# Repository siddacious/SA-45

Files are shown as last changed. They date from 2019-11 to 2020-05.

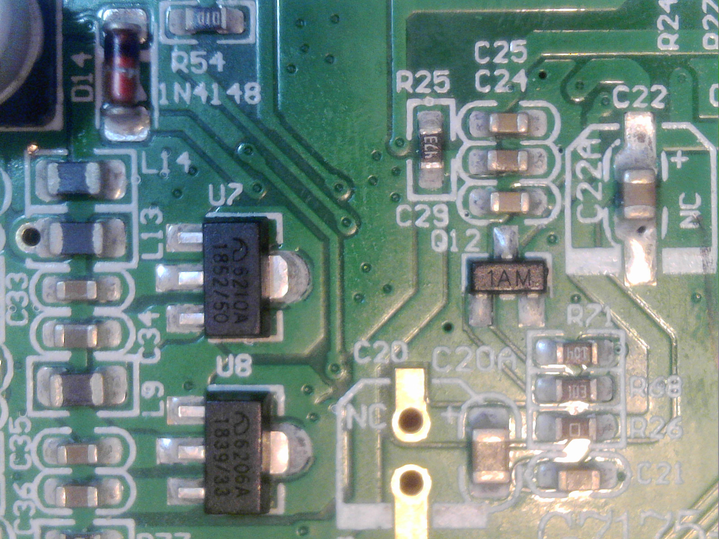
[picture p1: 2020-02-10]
images/S20190909_008.jpg

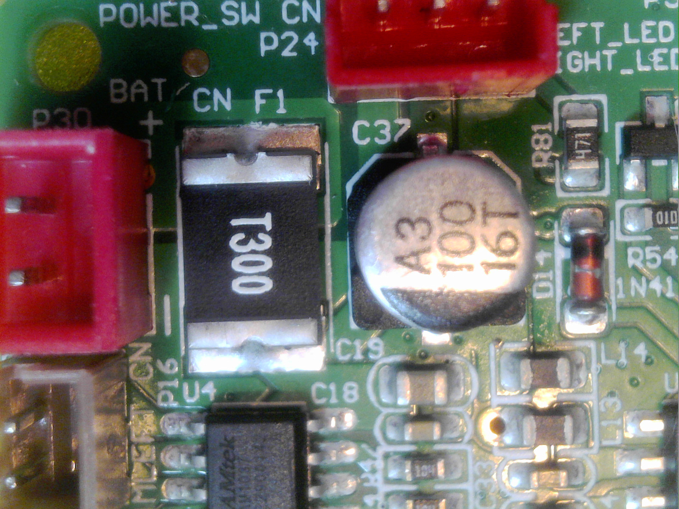
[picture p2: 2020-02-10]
images/S20190909_004.jpg

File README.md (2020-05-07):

# SA-45 - Useful info for playing doctor with your robot friend

All Software is released under the MIT license. See [MIT.txt](MIT.txt)

All Schematics and artwork is released as CC-BY-SA 4.0. See [CC-BY-SA_40.txt](CC-BY-SA_40.txt)

* [`droid-bb8_schematic.pdf`](droid-bb8_schematic.pdf) by @russdill
* [`nrf_extract/`](nrf_extract/) by @ruthsaurian
* [`nrf_extract_edits`](nrf_extract_edits/) by @siddacious and @ruthsaurian
* all other content by @siddacious

## More cool stuff
* by @russdill [here](https://github.com/russdill/droid_depot)
* by @ruthsaurian [here](https://github.com/ruthsarian/pxt-swge-beacon)
* SWGE discord: https://discord.gg/nsa9wCz

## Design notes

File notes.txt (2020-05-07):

# reference:
https://blog.includesecurity.com/2015/11/NordicSemi-ARM-SoC-Firmware-dumping-technique.html
https://www.pentestpartners.com/security-blog/nrf51822-code-readout-protection-bypass-a-how-to/

# Includes how to convert a .bin to 
https://ncrmnt.org/2019/04/14/note-to-self-how-to-flash-bin-files-via-raw-gdb/

# openocd startup using j-link
openocd.exe -f interface\jlink.cfg  -c "transport select swd" -c "adapter_khz 6000" -f target\nrf51.cfg

# openocd command to reset and halt the processor
reset halt

# scripts
# for me, found instructions that didn't help or I used wrong. Ended up using the instruction and register that Ruthsarian used -sidd
drop.py   : searches for an instruction that will write contents of a memory address to 

# original version switches the endianness
pickup.py : using the instruction found with drop.py, will read back the contents of flash memory

# Command to convert the extracted .bin to .hex for programming:
arm-none-eabi-objcopy -I binary -B arm -O ihex -S backup.bin backup.hex

#to program via SWD & JLink:
nrfjprog -f nrf51 --program backup.hex

[9:24 PM]  Ruthsarian: my basic understanding is there are two serial lines (each with their own clock, so 4 wires total) between the bluetooth and audio microcontrollers. i did do several captures on those lines with a logic analyzer.
bluetooth controller sends commands to the audio controller to tell it what to play. those commands come in the form of two bytes. the first byte is the command (THIS IS ALL ASSUMPTION based on what I've seen) which is always 0x10 followed by a second byte which identifies which group of audio clips the audio controller should play from.
[9:24 PM]  Ruthsarian: at startup or when a new personality chip is inserted, there is a bunch more data that is send between them. i can pick out personality chip ID and affiliation ID from them.
[9:25 PM]  Ruthsarian: but without any captures from an R2 I can't confirm whether or not there's a difference (such as a "HEY I'm an R2!"
[9:26 PM]  Cowkitty | Dead Bothans: @Mia Honestly, I’d recommend a different approach: we’ve confirmed the droid controller sends different commands per button, so it’s the BB firmware that’s deciding to just use the accessory unique button code to play sounds. I’d look into seeing what the firmware does when it sees that button code, and look into modding that. Problem is you might not have a pin already wired/accessible to send power to like the R2 units. Not sure— we haven’t done a tear down on both to compare yet.
[9:26 PM]  Ruthsarian: also, with the bb unit at least, that 'play sound' command is the same whether you're pressing the 'accessory' or sound button.
[9:27 PM]  Ruthsarian: from bb's bluetooth microcontroller to the audio controller
[9:29 PM]  Cowkitty | Dead Bothans: Gotcha. Yeah, that’s what I said above. Bb heard unique command from remote, and says “play sound” instead of “power to accessory pin”
[9:30 PM]  Mia: Yeah, that's my ultimate goal, finding the input routine and making the accessory button into a call to "play from blaster sound bank" instead of "play from random sound bank." But to get a breakpoint in there I think I'm gonna have to figure out when it's making a call to the sound chip, then roll up the stack.
[9:31 PM]  Ruthsarian: i've seen schematics that others have made of the bb and r2 hardware. the pinouts for the bluetooth controller are very similar. differences being the accessory detection pins on the R2 are used to read the trimpot in the BB unit. belief being the trimpot controls balancing the two motors in the BB unit so it drives straight.
[9:31 PM]  Cowkitty | Dead Bothans: @Ruthsarian Yeah, that’s what I feared. I didn’t think they’d waste a pin on the BB for that

[9:12 AM]  Mia: You have anything written down about, like, what byte the command is, or what it responds with to represent the two models?
[9:12 AM]  Russ: the serial register for droid model is reg 0x01
[9:12 AM]  Russ: bb series is 2, r2 series is 1
[9:40 AM]  Cowkitty | Dead Bothans: Check the spreadsheet. Already proven those same identifiers are used as beacons, sans chips.
[9:58 AM]  Russ: I know, that one comes from the personality chip
[9:58 AM]  Russ: the default personality chip in the generalplus rom
[9:59 AM]  Russ: hence you only get the value from the installed personality chip instead when one is inserted
[9:59 AM]  holapenguin: if no chip, you can tell.  if has chip, you can't tell, from a beaconing point of view. you're both saying the same thing, no confusion
[10:02 AM]  Russ: the issue is that there are two different droid identifiers. One the droid uses internally, and the other that is tied to the personality chip
[10:41 AM]  Ruthsarian: I did put a logic analyzer on the lines between the nRF (bluetooth) and GP (audio) microcontrollers in the BB droid a while back. I believe there are two separate serial channels (each channel consisting of data line and a clock line). Each channel is one-way. So there's the line from nRF to GP and a second line, GP to NRF. Treating these lines as such, when I 'decode' the data, this is an example of the data I see.
On power on w/no personality chip
    (from gp to nrf)    00 00 00 00 02 00 00 02 00 00 01 00 00 00 00 00 00
    (from nrf to gp)    00 00 01 00 00 08 00 00 0a 00 00 00 00 42 02 0e 1c

On power on w/personality chip (black)
    (from gp to nrf)    80 00 80 00 02 80 00 08 80 00 09 80 00 80 00 80 00
    (from nrf to gp)    00 00 01 00 00 08 00 00 0a 00 00 00 00 42 02 0e 1c

On personality chip insertion (purple)
    (from gp to nrf)    80 00 80 00 07 80 00 01
    (from nrf to gp)    00 00 08 00 00 0a 00 00

On removal of personality chip
    (from gp to nrf)    00 00 00 00 02 00 00 01
    (from nrf to gp)    00 00 08 00 00 0a 00 00

On audio button press
    (from gp to nrf)    80 00
    (from nrf to gp)    10 00
[10:43 AM]  Ruthsarian: However, the audio button press data, for example, matches up with what audio plays. 0x10 being the command to play an audio clip. Then the byte that follows it identifying the group to play an audio clip from (that value being zero-indexed, so 0x00 = audio group 1)
[10:44 AM]  Ruthsarian: and the personality chip insertion and removal seems to include data that matches with the chip being inserted (chip ID and affiliation ID)
[10:45 AM]  Ruthsarian: when reacting to a beacon, the data looks the same as a button press. meaning the nRF chip tells the GP chip what audio group to play from.
[10:57 AM]  Ruthsarian: my interpretation of what the key bytes of the data are
    power on, gp to nrf:
        byte  5 = droid type
        byte  8 = personality chip
        byte 11 = affiliation

    change of personality chip, gp to nrf:
        byte 5 = new personality chip
        byte 8 = affiliation

    play audio (nrf to gp):
        byte 2 = audio group to play from
[11:12 AM]  Russ: @Ruthsarian there's a 5th serial line that the generalplus uses to notify the nrf, eg, when there is a new personality chip
[11:13 AM]  Ruthsarian: is it serial, or is it just change state to notify there's a change. i did see that line and i analyzed it, but i didn't see data on it, just an occasional change in state
[11:14 AM]  Russ: it's like an interrupt
[11:15 AM]  Russ: each serial transaction is an exchange, write byte while reading byte.
[11:15 AM]  Russ: for a reg read, it writes the register to read while reading back a byte it throws away, then writes a zero while reading back the byte
[11:16 AM]  Russ: for reg write, it writes the reg to write while reading back a byte it throws away, then writes the value while reading a value it throws away
[11:16 AM]  Russ: I suspect that the register number indicates where it is going to be a read or a write
[11:17 AM]  Ruthsarian: that is a personality chip being inserted event. the top signal is that 5th line you were talking about.
[11:18 AM]  Russ: 1, 8, and 10 are the only registers I see as read registers
[11:18 AM]  Russ: (droid type, personality chip, affiliation)
[11:19 AM]  Russ: oh, and 0, which seems to be a status bitfield
[11:24 AM]  Mia: So what distinguishes a write on this protocol from a read? Is that image then the lower device saying to the upper device “write register 8: 0000, then write register A: 0000”?
[11:24 AM]  Russ: afaik it's just the register number
[11:25 AM]  Russ: hmm...actually it could be the middle exchange, forgot about that one
[11:25 AM]  Russ: read has three exchanges
[11:26 AM]  Russ: write has 2
[11:26 AM]  Russ: the pattern might just be, exchange 1 - register, exchange 2 - write byte, exchange 3 - read byte
[11:27 AM]  Mia: Hmm. So the difference is then that for a write you just throw away whatever you get back as the read.
[11:27 AM]  Russ: for writes it just does 2 exchanges
[11:30 AM]  Russ: and it looks like on the first exchange the status byte is always returned
[11:44 AM]  Ruthsarian: @Russ the droid type is in register 1? by register do you mean register 1 of the cortex-m0 at the center of the nrf or is that value being stored somewhere else? and can you tell whether or not that value is being checked every time a button press is received? in other words, if I had a debugger connected, could I modify that register value to make the droid think it's another droid?
[11:44 AM]  Russ: the gp
[11:44 AM]  Russ: so you see on the nrf transmit, its 01 00 00, and then from the gp 00 00 02
[11:44 AM]  Russ: that's reading value 2 from reg 1
[11:45 AM]  Russ: there's several droid config things that only happen during boot
[12:48 PM]  holapenguin: for all, see this if you're wanting to use ghirdra collaboratively https://medium.com/@jannis.kirschner/ghidra-collaborative-reversing-1-2-how-to-setup-a-ghidra-server-711f4212912e

 https://discord.gg/pgeEQd

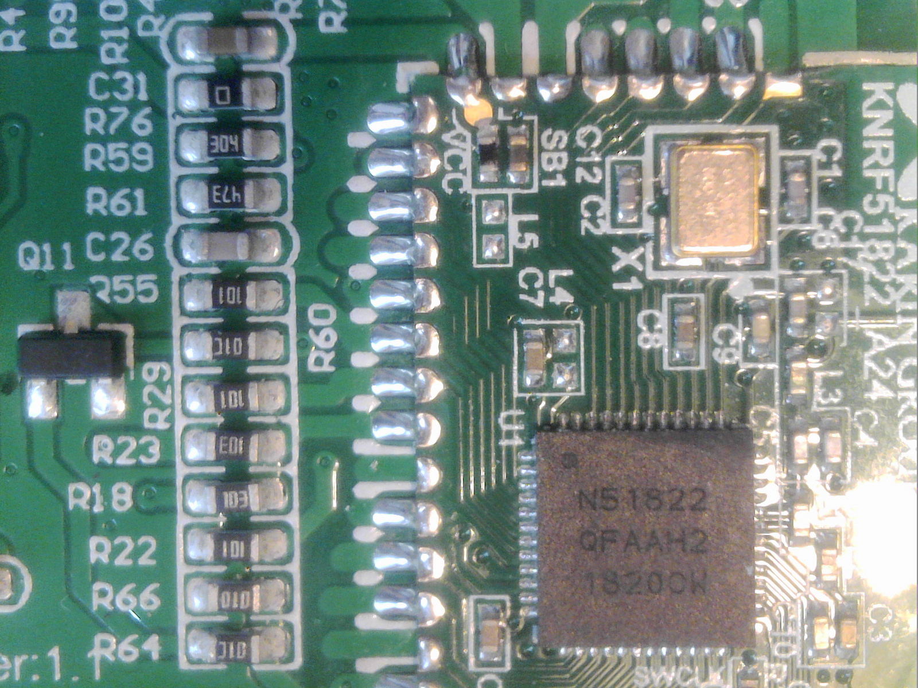
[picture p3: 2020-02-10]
images/S20190909_013.jpg

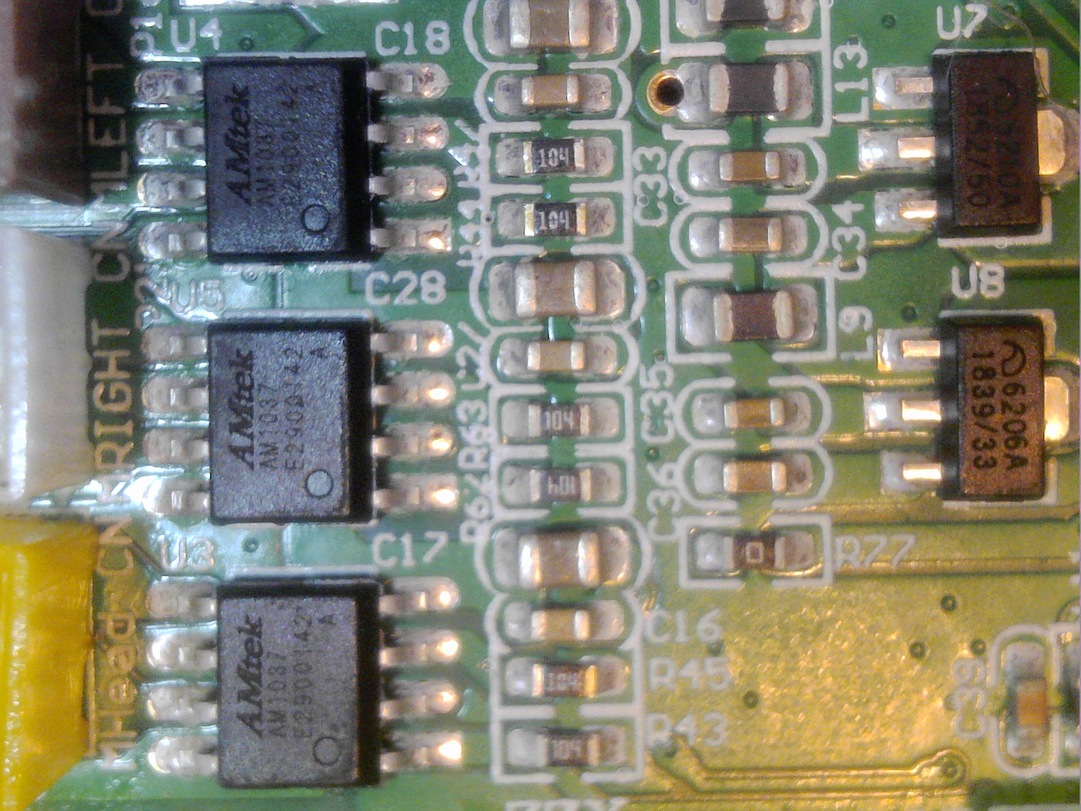
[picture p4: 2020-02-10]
images/S20190909_005.jpg

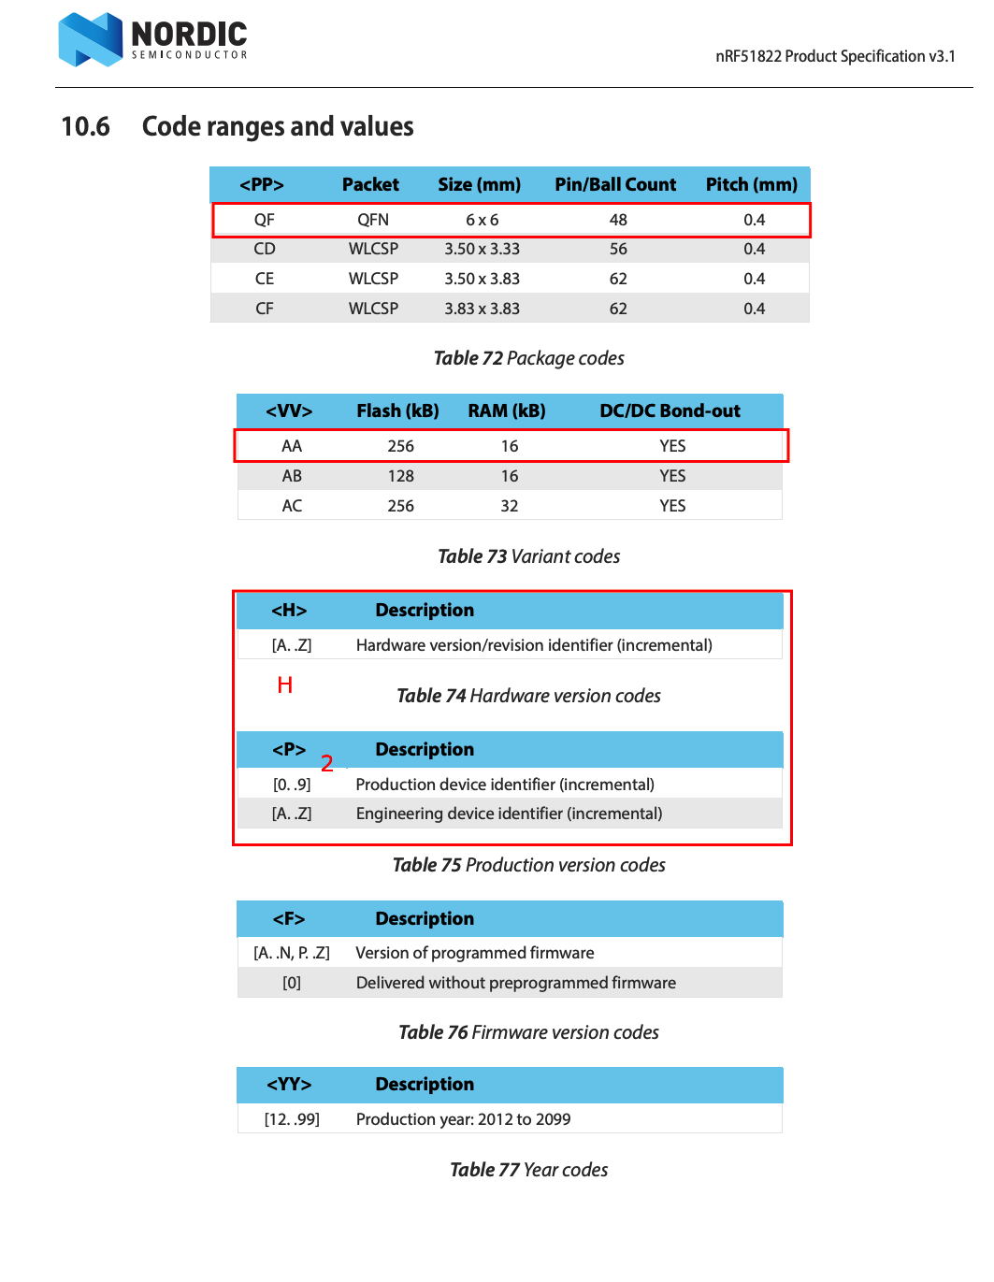
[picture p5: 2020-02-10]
images/nrf_version_info.png

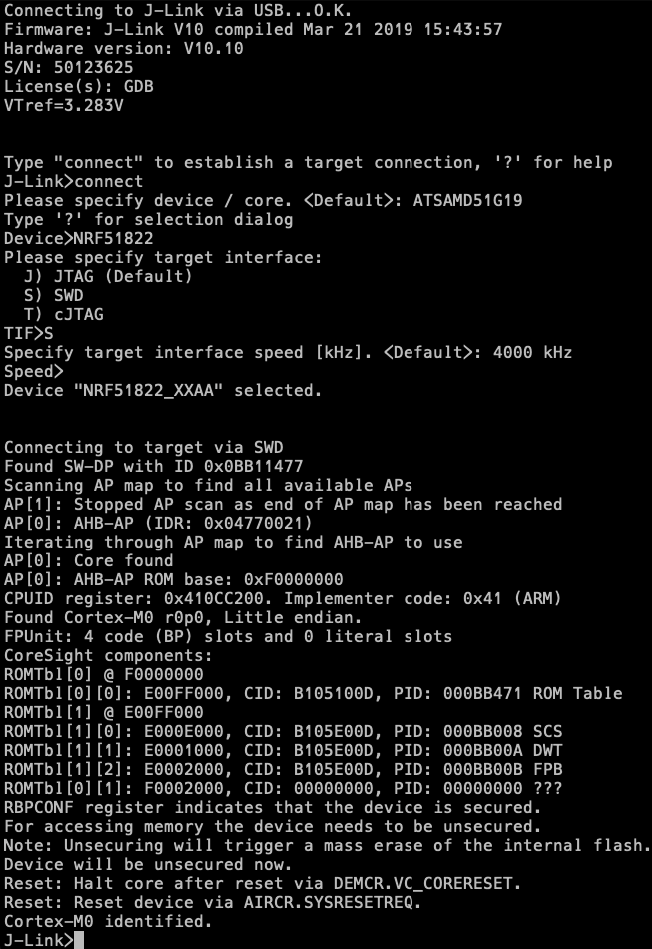
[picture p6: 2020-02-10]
images/initial_connect_nrf.png

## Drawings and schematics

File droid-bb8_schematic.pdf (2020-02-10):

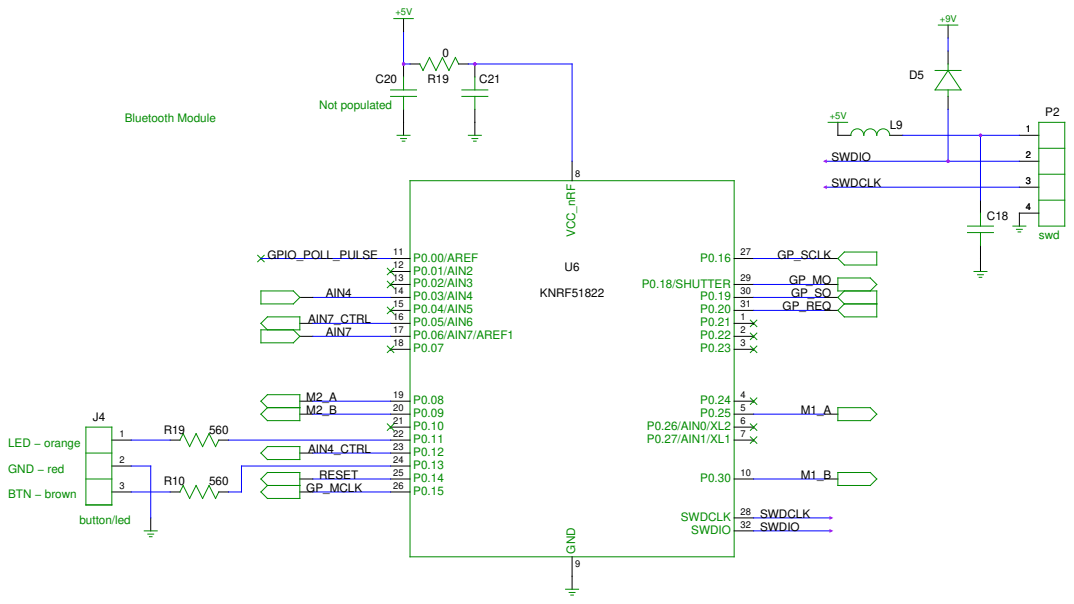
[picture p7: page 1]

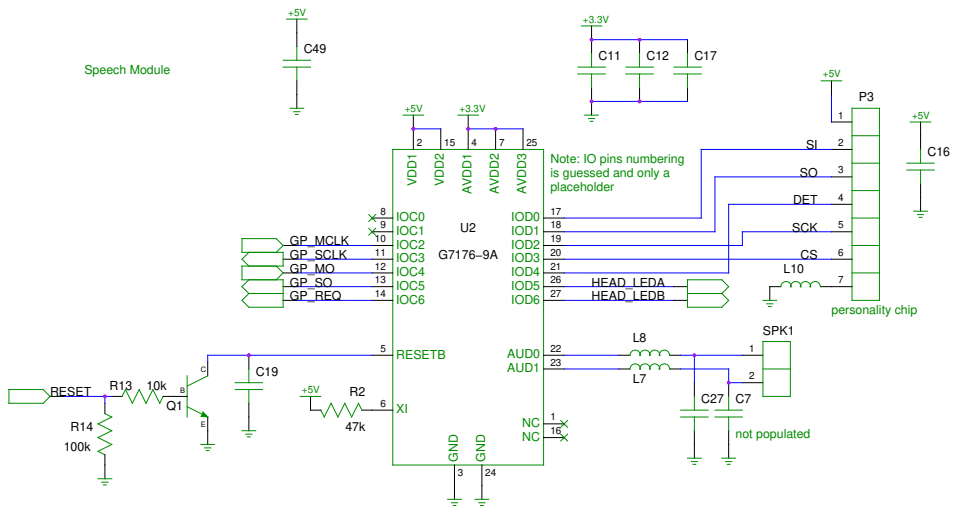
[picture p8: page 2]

Note: IO pins numbering
is guessed and only a
placeholder

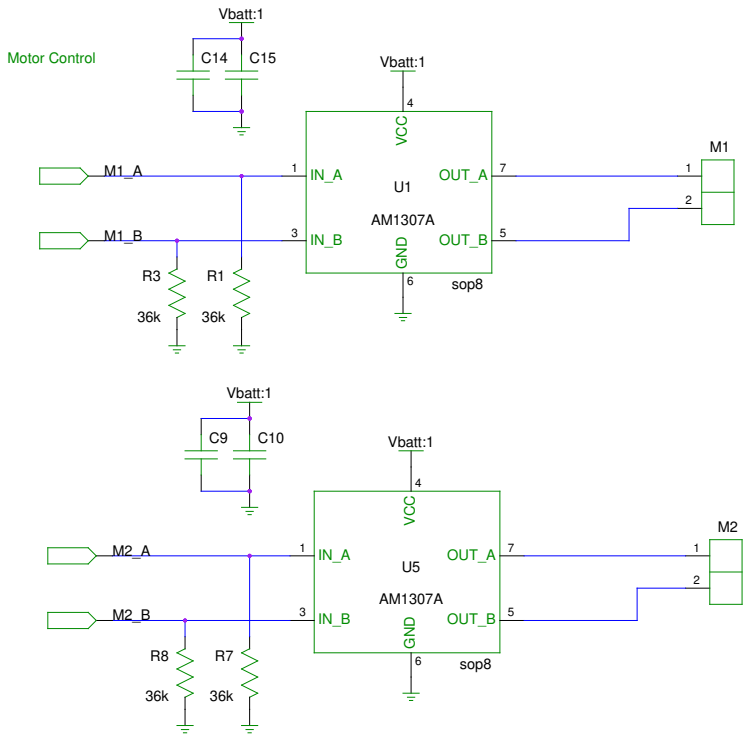
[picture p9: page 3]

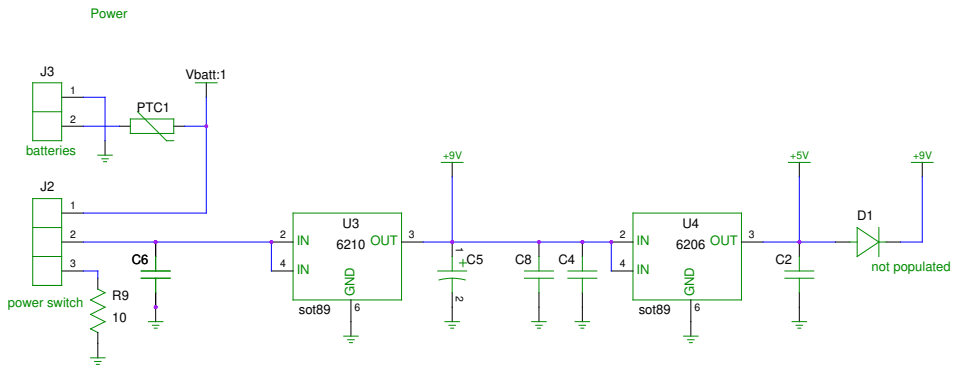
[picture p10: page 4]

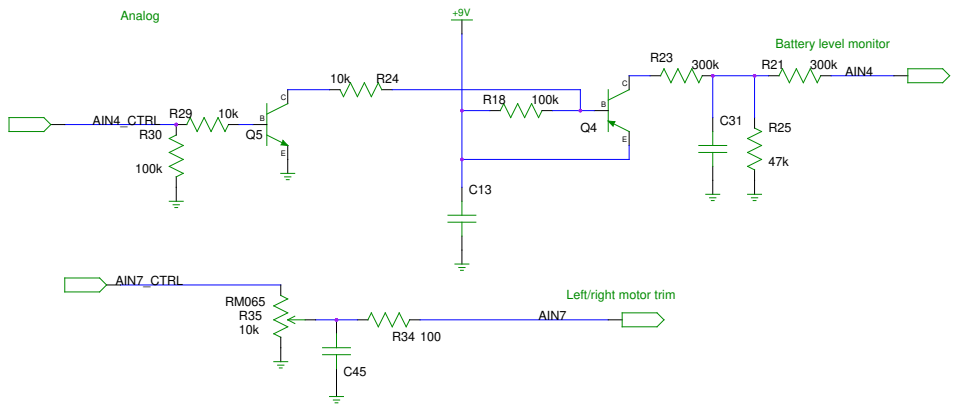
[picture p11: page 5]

Left/right motor trim
AIN7

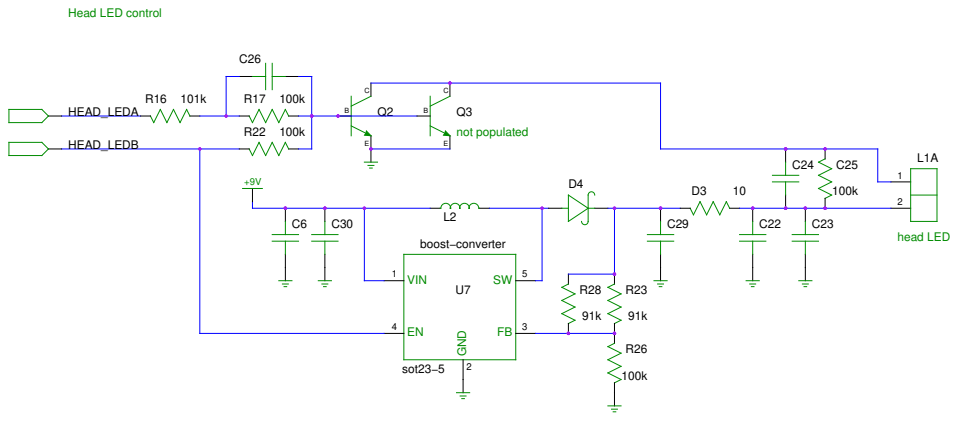
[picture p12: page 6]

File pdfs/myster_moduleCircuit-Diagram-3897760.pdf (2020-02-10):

# Dome Socket

# Main

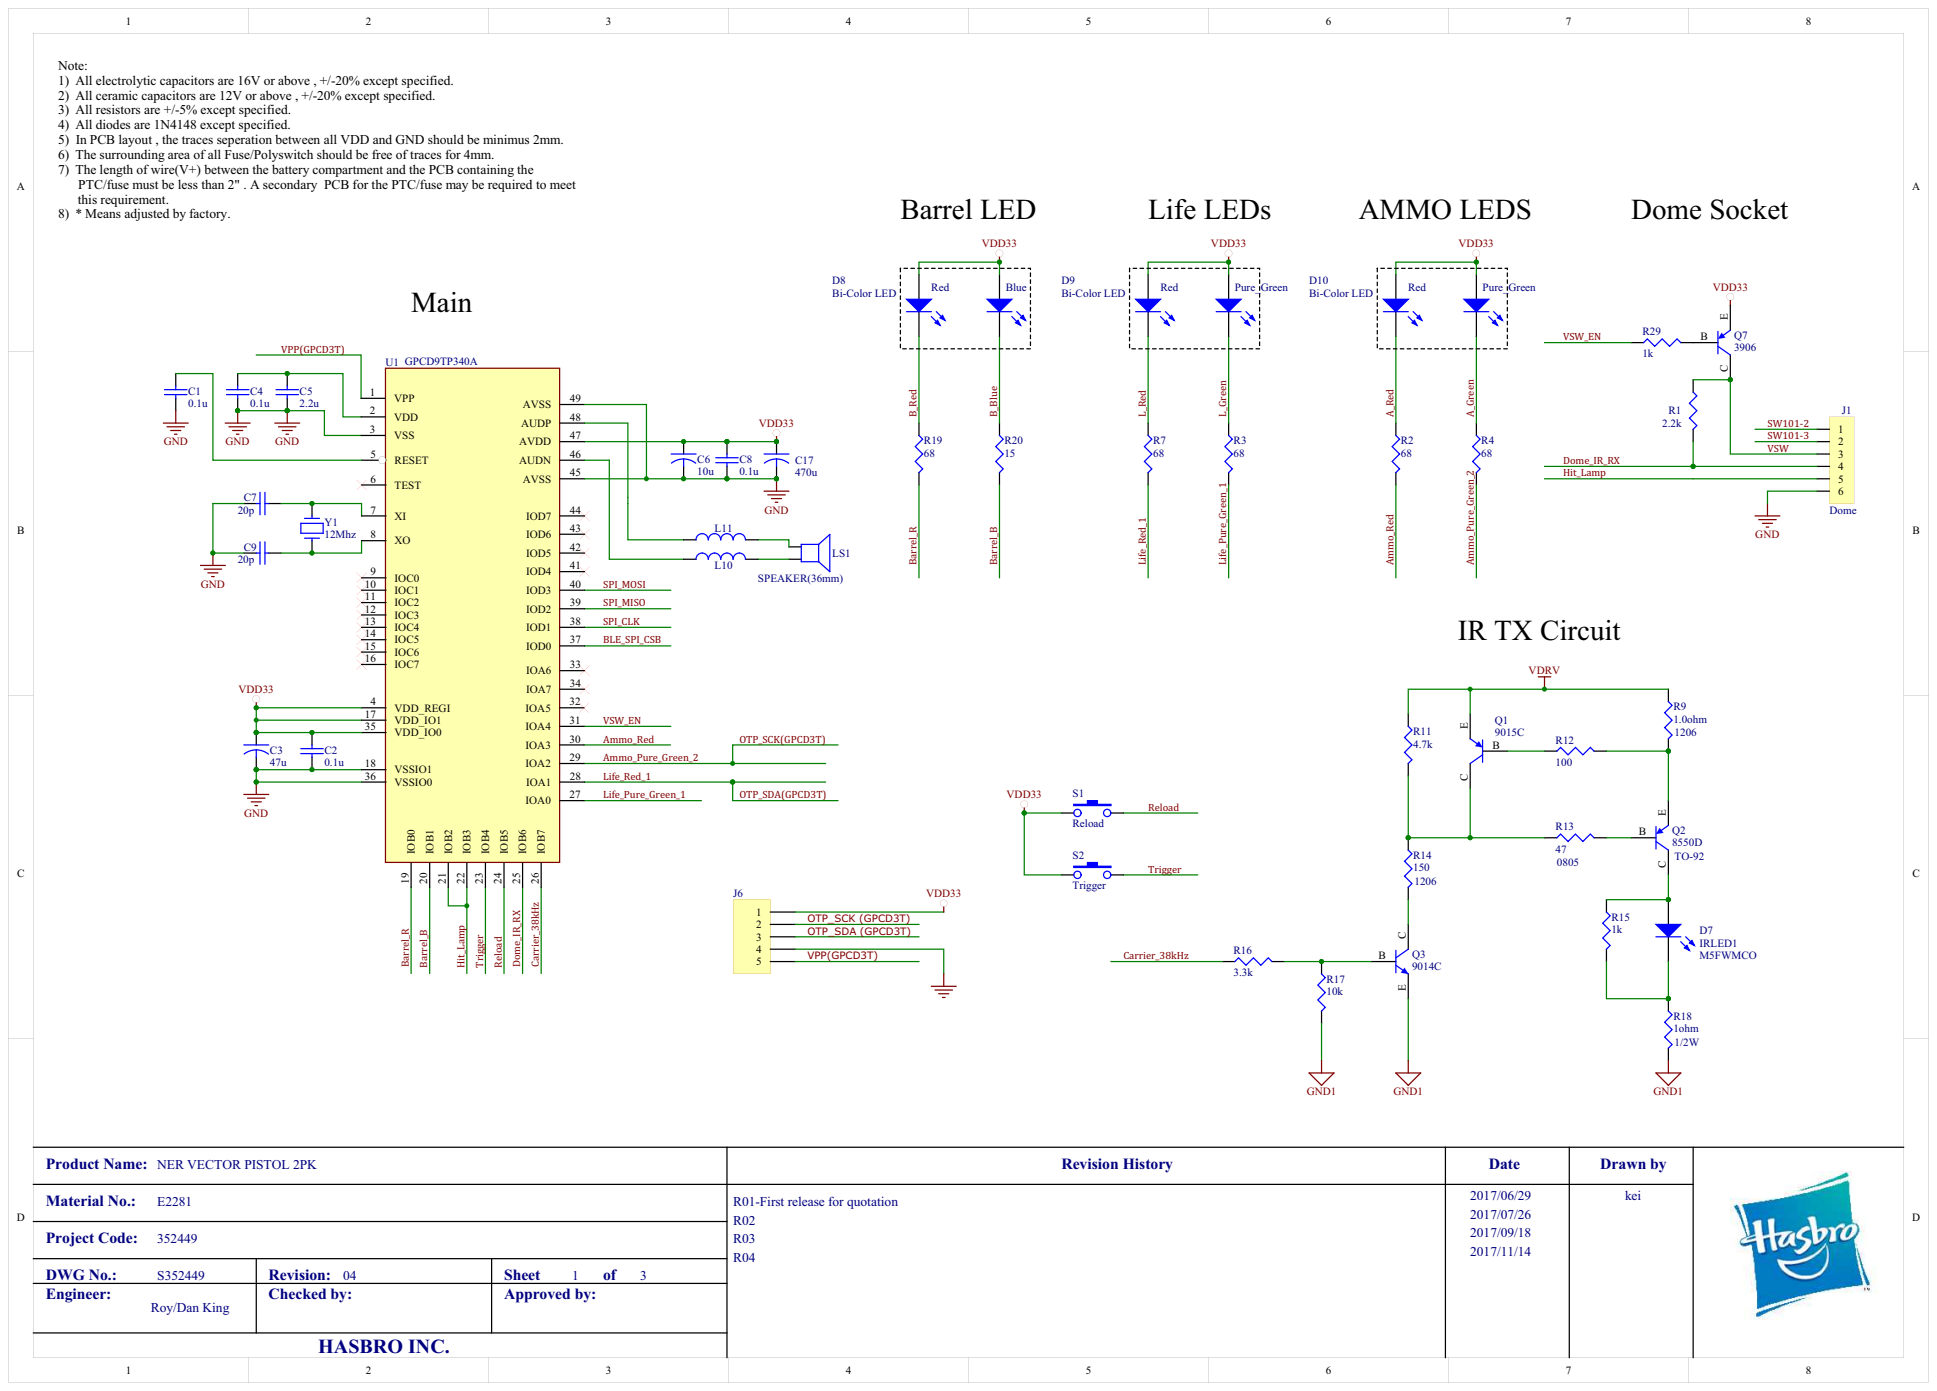
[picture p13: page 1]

Note:
1) All electrolytic capacitors are 16V or above , +/-20% except specified.
2) All ceramic capacitors are 12V or above , +/-20% except specified.
3) All resistors are +/-5% except specified.
4) All diodes are 1N4148 except specified.
5) In PCB layout , the traces seperation between all VDD and GND should be minimus 2mm.
6) The surrounding area of all Fuse/Polyswitch should be free of traces for 4mm.
7) The length of wire(V+) between the battery compartment and the PCB containing the
PTC/fuse must be less than 2" . A secondary PCB for the PTC/fuse may be required to meet
this requirement.
8) * Means adjusted by factory.

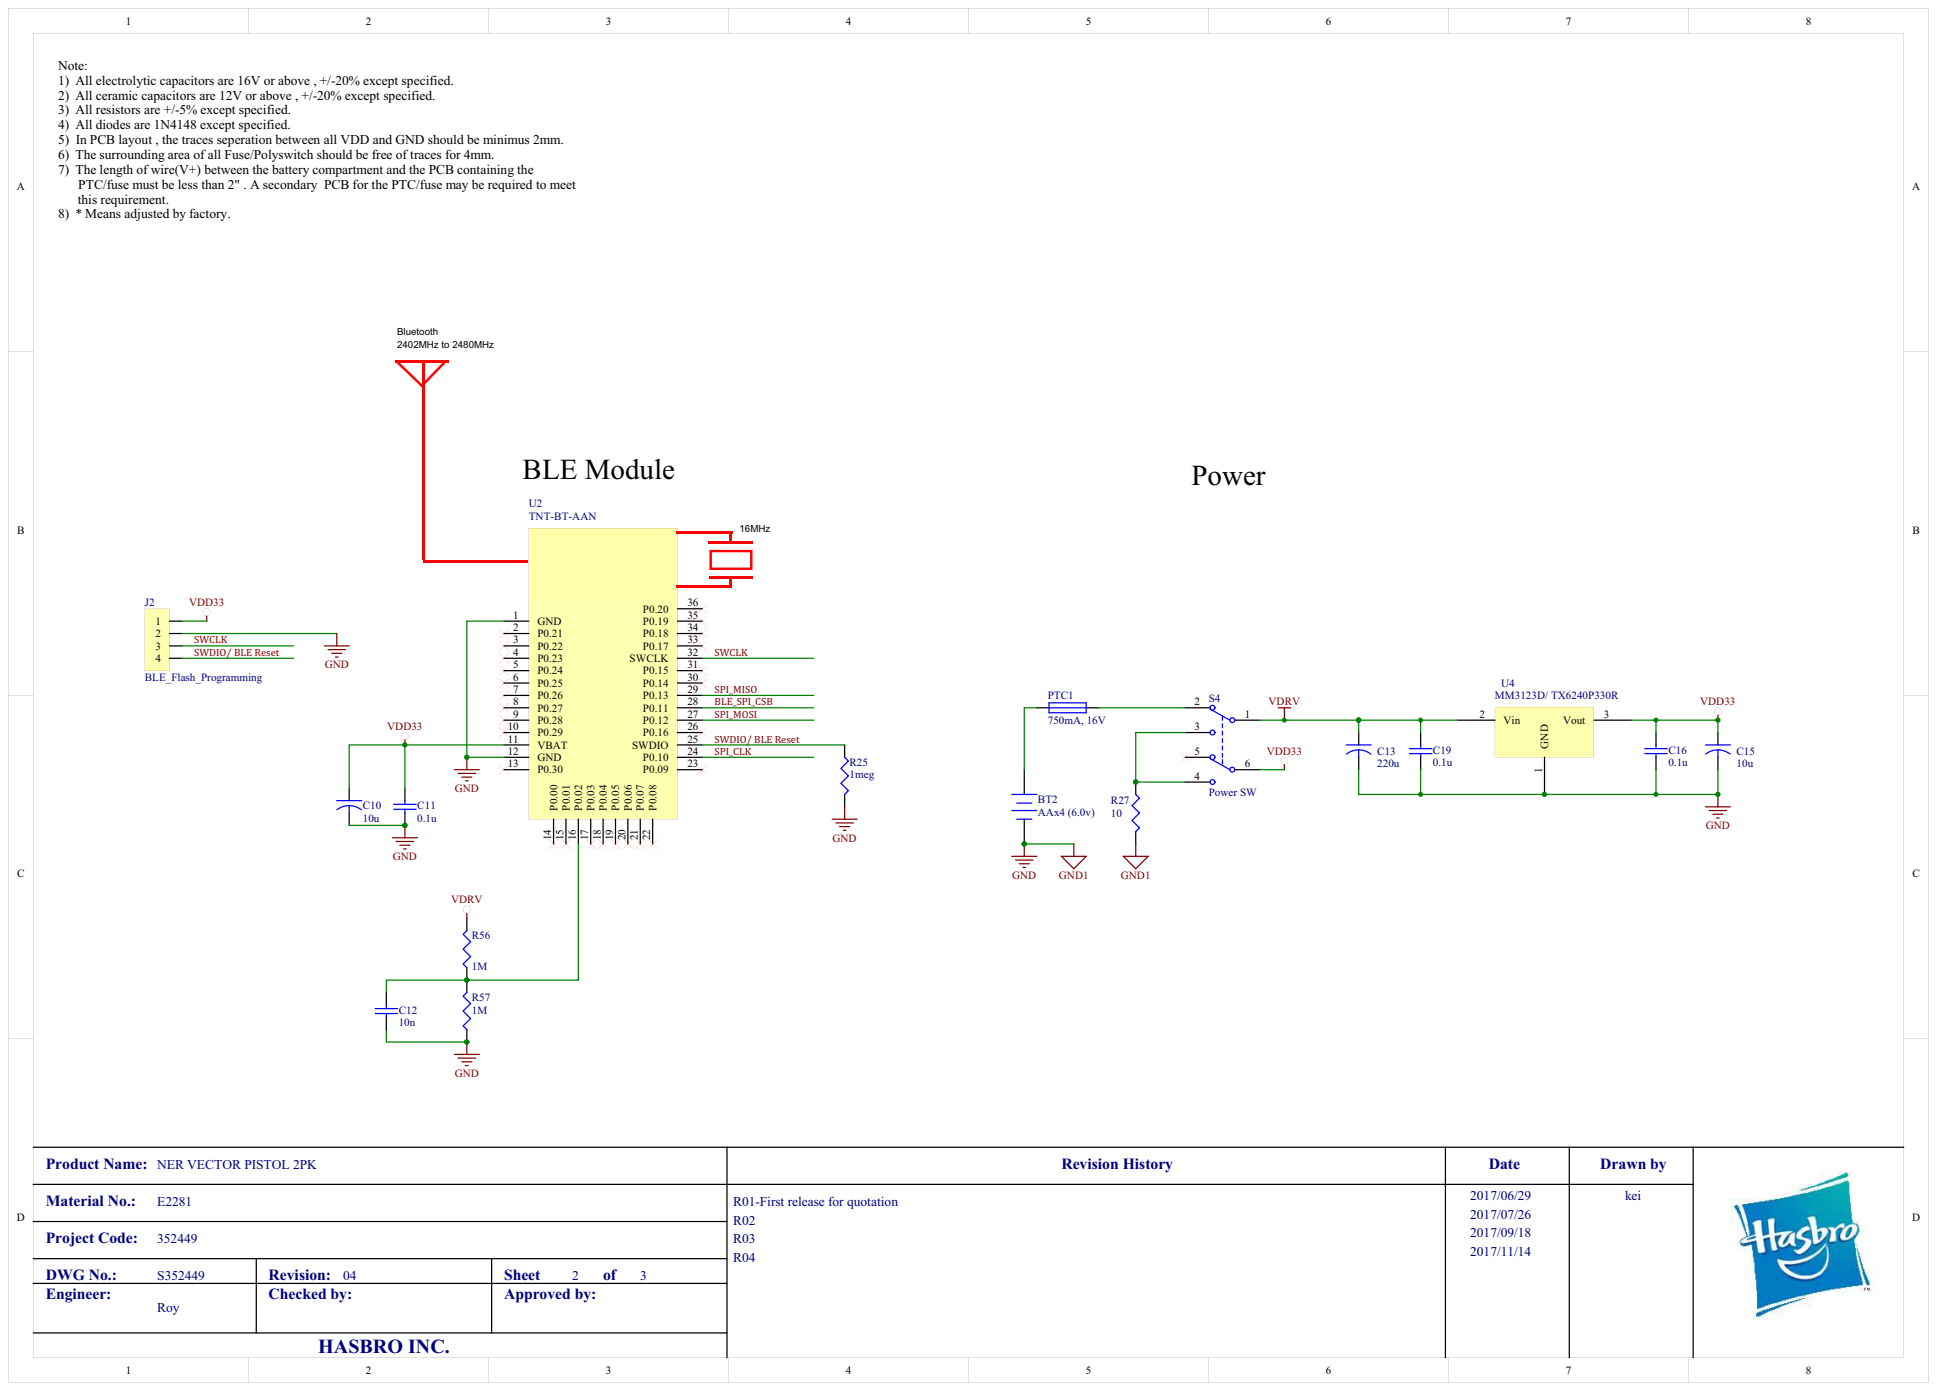
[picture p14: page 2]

4) All diodes are 1N4148 except specified.
5) In PCB layout , the traces seperation between all VDD and GND should be minimus 2mm.
6) The surrounding area of all Fuse/Polyswitch should be free of traces for 4mm.
7) The length of wire(V+) between the battery compartment and the PCB containing the
PTC/fuse must be less than 2" . A secondary PCB for the PTC/fuse may be required to meet
this requirement.
8) * Means adjusted by factory.

# Dome PCB

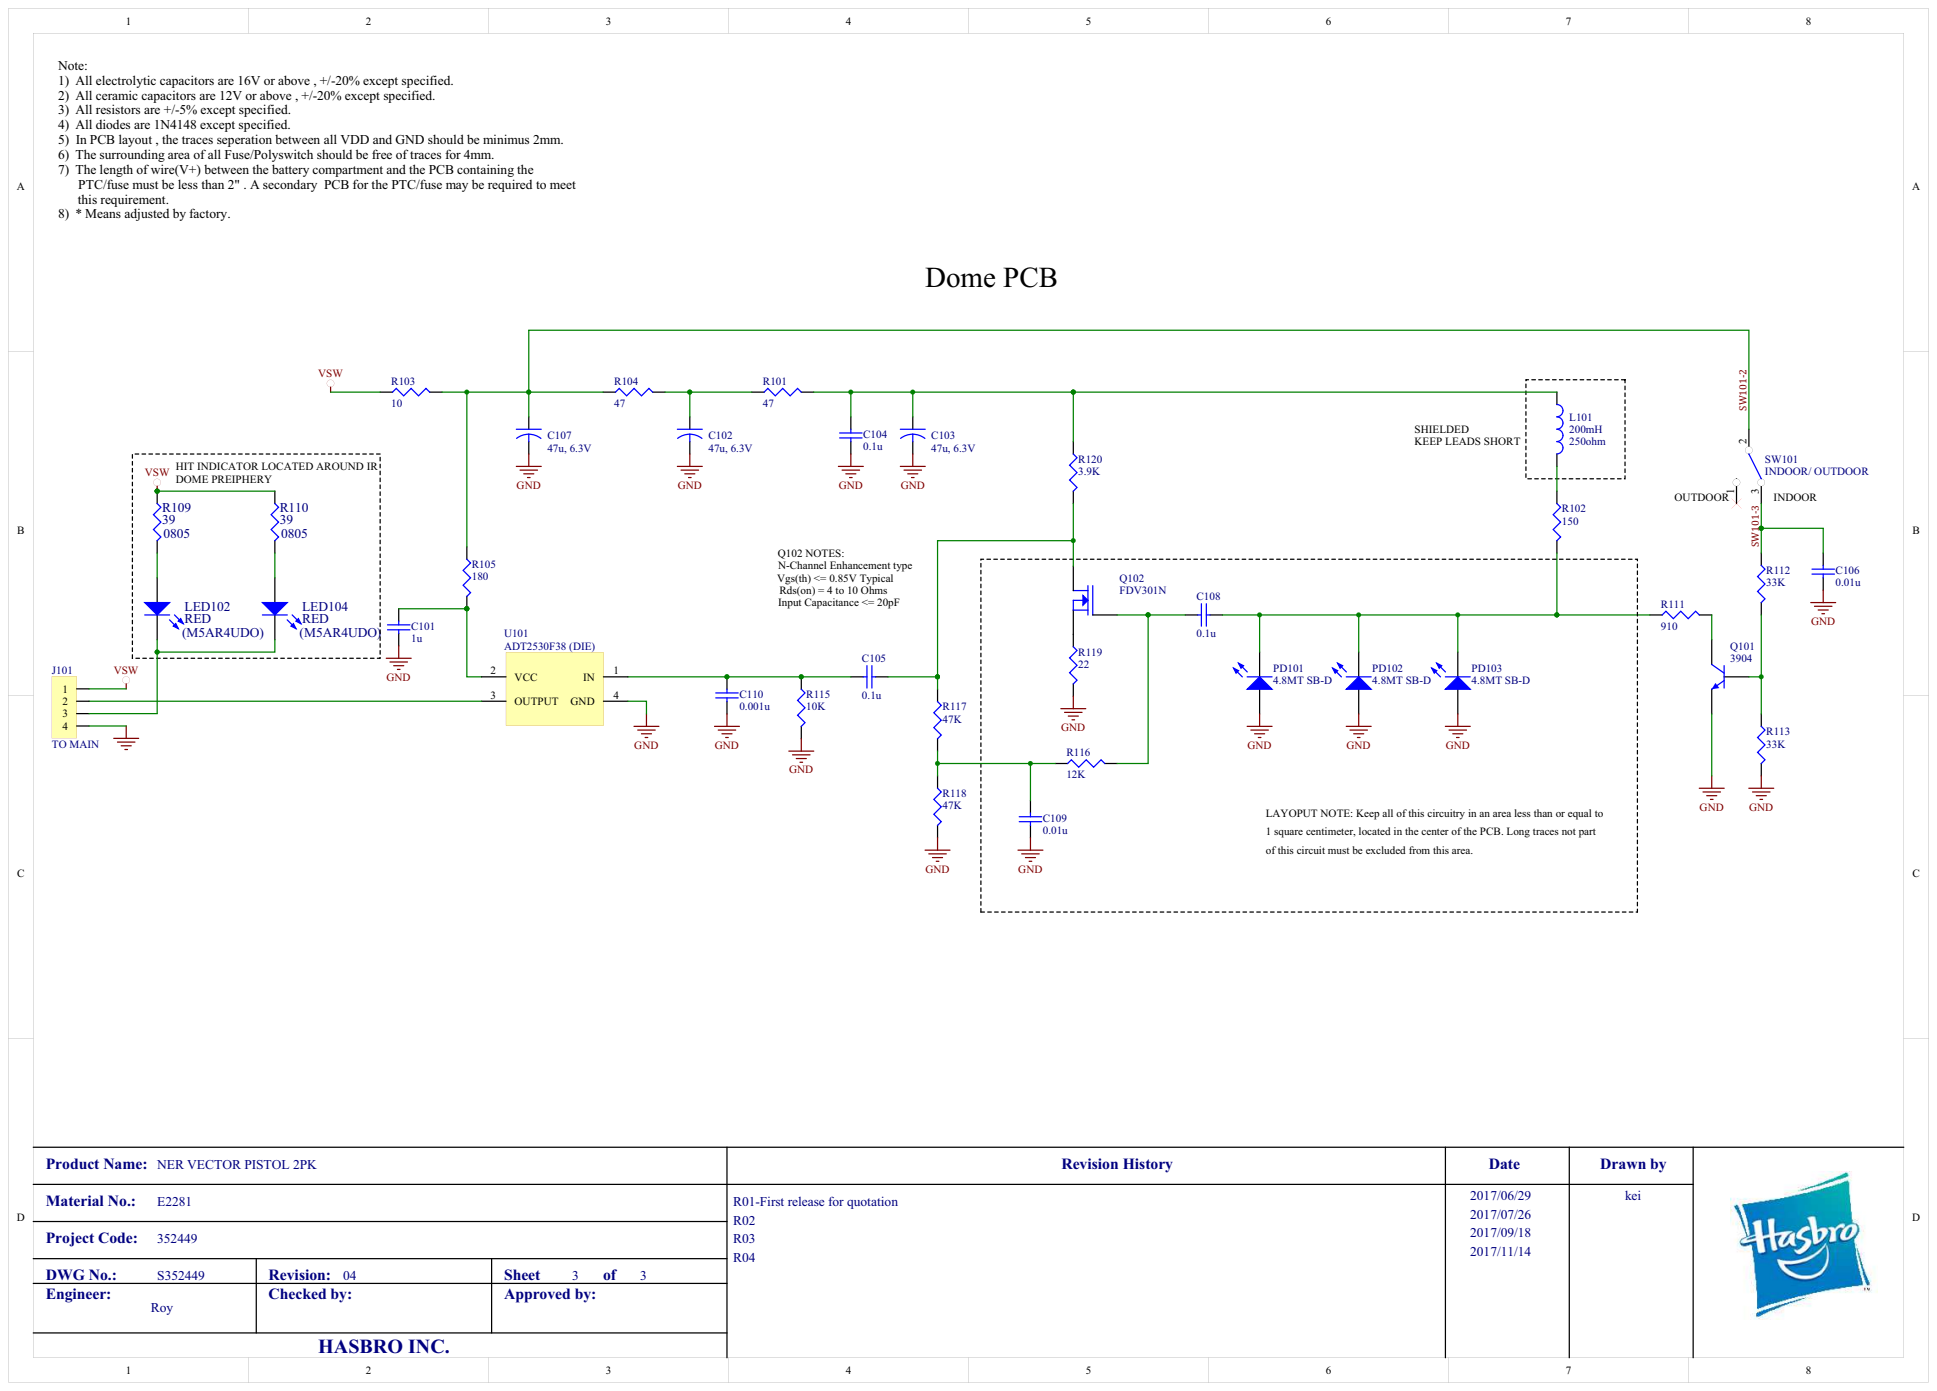
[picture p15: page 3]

4) All diodes are 1N4148 except specified.
5) In PCB layout , the traces seperation between all VDD and GND should be minimus 2mm.
6) The surrounding area of all Fuse/Polyswitch should be free of traces for 4mm.
7) The length of wire(V+) between the battery compartment and the PCB containing the
PTC/fuse must be less than 2" . A secondary PCB for the PTC/fuse may be required to meet
this requirement.
8) * Means adjusted by factory.

HIT INDICATOR LOCATED AROUND IR
VSW
DOME PREIPHERY

Q102 NOTES:
N-Channel Enhancement type
Vgs(th) <= 0.85V Typical
Rds(on) = 4 to 10 Ohms
Input Capacitance <= 20pF

LAYOPUT NOTE: Keep all of this circuitry in an area less than or equal to
1 square centimeter, located in the center of the PCB. Long traces not part
of this circuit must be excluded from this area.

- 9 -

## TNT-BT-AAN

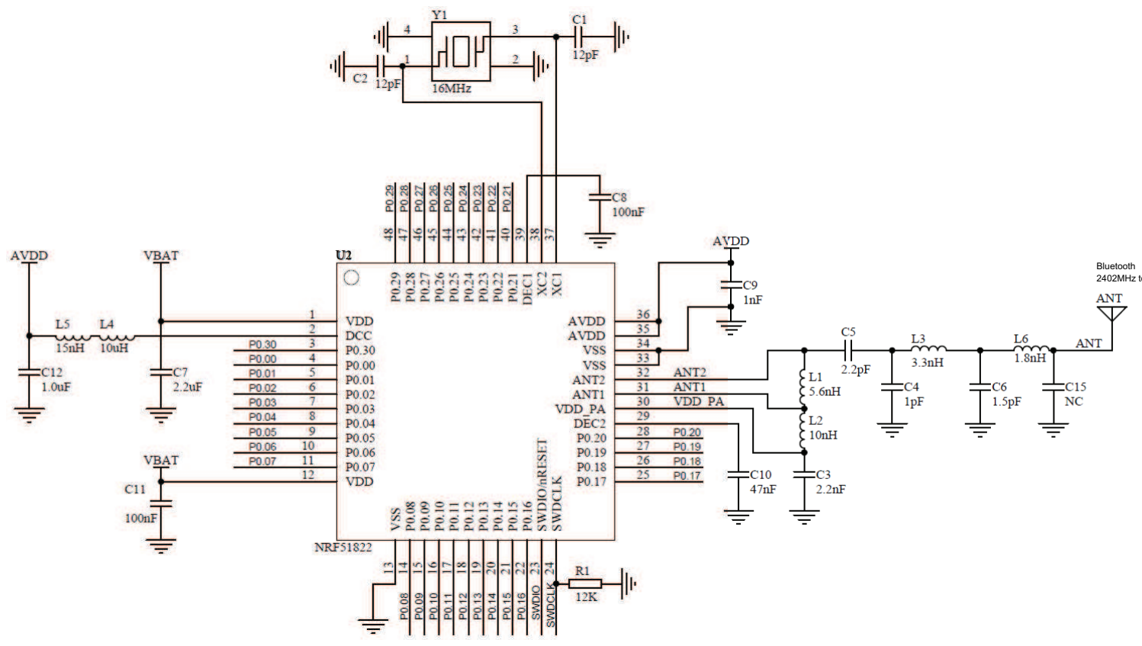
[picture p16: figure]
Bluetooth

2402MHz to 2480MHz

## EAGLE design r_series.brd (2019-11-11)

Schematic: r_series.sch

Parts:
C11, C16, C18, C21, C23, C24, C25, C26, C27, C29, C31, C33, C34, C35, C36, C38, C39: CAP_CERAMIC0603_NO; 0603-NO
C17, C19, C20A, C22A, C28: CAP_CERAMIC_0805MP; _0805MP
C37: 100uF; PANASONIC_D
D14: DIODESOD-323; SOD-323
F1: PTC1812
JP1, JP2, JP3, JP4, JP5, JP6: HEADER-1X2ROUND; 1X02_ROUND
JP7, JP8, JP9: HEADER-1X3ROUND; 1X03_ROUND
JP10, JP11, JP12: HEADER-1X4ROUND; 1X04_ROUND
JP13, JP14: HEADER-1X5ROUND; 1X05_ROUND
JP15: HEADER-1X6ROUND; 1X06_ROUND
L9, L13, L14: INDUCTOR0805-NO; 0805-NO
L11, L12: INDUCTOR0603_NO; 0603-NO
Q6, Q10, Q13, Q14: TRANSISTOR_PNPSOT23-REFLOW; SOT23-R
Q11, Q12: TRANSISTOR_NPNWIDE; SOT23-WIDE
R5: 330; 0603-NO
R6, R7, R22, R29, R49, R51, R52, R54, R55, R60, R64, R66: 100; 0603-NO
R18, R23, R68: 10K; 0603-NO
R25, R61: 47K; 0603-NO
R27, R99, R100: 1K; 0603-NO
R43, R44, R45, R47_OR_42, R62, R63, R71: 100K; 0603-NO
R59: 300K; 0603-NO
R81: 470; _0805MP
U7, U8: ME62XX; SOT89
U$1, U$2, U$3: AM1037A; SOIC8_208MIL
U$4: KNRF51822_A24; KNRF51822
U$5: GPCD9TP340A_DROID; GPCD9TP340A

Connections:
3.3V: C24.2, C25.2, C36.2, R25.1, U8.2 (VOUT), U8.2@1 (VOUT)
5V: C20A.2, C21.2, C22A.2, C23.2, C33.2, L9.2, Q6.2 (E), Q13.2 (E), Q14.2 (E), U7.2 (VOUT), U7.2@1 (VOUT)
9V_IN: C34.2, L13.2, Q10.2 (E), R54.1, U7.1 (VSS)
BAT+: F1.P$2 (2), JP2.2
DET: JP15.3, U$5.29
GND: C11.1, C16.1, C17.1, C18.1, C19.1, C20A.1, C21.1, C22A.1, C23.1, C24.1, C25.1, C26.2, C27.1, C28.1, C29.1, C31.1, C33.1, C34.1, C35.1, C36.1, C37.-, C38.1, C39.1, JP2.1, JP7.2, JP8.2, JP11.2, JP12.1, JP14.2, JP15.6, L14.1, Q11.2 (E), Q12.2 (E), R5.1, R43.1, R44.1, R45.1, R47_OR_42.1, R61.2, R62.1, R63.1, R66.1, R71.1, R81.1, U8.3 (VIN), U$1.6 (GND), U$2.6 (GND), U$3.6 (GND), U$4.P$9 (P0.29), U$5.3, U$5.8, U$5.24, U$5.30, U$5.34
GND_INDUCTED: L14.2, U7.3 (VIN)
HEAD_IN_A: R43.2, U$3.1 (IN_A), U$4.P$3 (P0.23)
HEAD_IN_B: R45.2, U$3.3 (IN_B), U$4.P$4 (P0.24)
HEAD_OUT_A: JP5.2, U$3.7 (OUT_A)
HEAD_OUT_B: JP5.1, U$3.5 (OUT_B)
HED_DET: JP1.1
HE_5V: JP13.5, Q6.3 (C)
H_DET: JP13.1, U$5.13
H_L: JP10.2, R52.1
H_MID: JP10.3, R49.1
H_R: JP10.1, R51.1
LED_B: JP13.2, U$5.12
LED_G: JP13.3, U$5.11
LED_R: JP13.4, U$5.10
LEFT_IN_A: R44.2, U$1.1 (IN_A), U$4.P$5 (P0.25)
LEFT_IN_B: R47_OR_42.2, U$1.3 (IN_B), U$4.P$10 (P0.30)
LEFT_OUT_A: JP3.2, U$1.7 (OUT_A)
LEFT_OUT_B: JP3.1, U$1.5 (OUT_B)
L_ID: JP8.1, R18.1, R22.1
L_LED: JP8.3, R6.1
MM_RESET: C29.2, Q12.3 (C), U$5.5
MM_RESET_OUT: R68.2, R71.2, U$4.P$25 (P0.14)
OFF: JP9.1, R81.2
P0.15: U$4.P$26 (P0.15), U$5.18
P0.17: U$4.P$28 (P0.17), U$5.20
P0.18: U$4.P$29 (P0.18), U$5.21
P0.19: U$4.P$30 (P0.19), U$5.22
PAIR_BTN: JP11.1, U$4.P$24 (P0.13)
PAIR_LED+: JP11.3, U$4.P$22 (P0.11)
PAIR_LED-: JP11.4, R5.2
Q6_B: Q6.1 (B), R27.1
Q10_B: Q10.1 (B), R54.2, R60.2
Q10_C: Q10.3 (C), R59.2
Q11_B: Q11.1 (B), R64.1
Q11_C: Q11.3 (C), R60.1
Q12_B: Q12.1 (B), R68.1
Q13_B: Q13.1 (B), R99.1
Q13_C: Q13.3 (C), R6.2
Q14_B: Q14.1 (B), R100.1
Q14_C: Q14.3 (C), R7.1
R22_B: R22.2, U$4.P$12 (P0.1)
R23_B: R18.2, R23.2, U$4.P$16 (P0.5)
R25_B: R25.2, U$5.6
R27_B: R27.2, U$5.9
R29_B: R29.2, U$4.P$15 (P0.4)
R49_B: R49.2, U$4.P$13 (P0.2)
R51_B: R51.2, U$4.P$2 (P0.22)
R52_B: R52.2, U$4.P$18 (P0.7)
R55_B: R55.2, U$4.P$14 (P0.3)
R61_A: C26.1, R55.1, R59.1, R61.1
R64_B: R64.2, R66.2, U$4.P$23 (P0.12)
R99_B: R99.2, U$5.14
R100_B: R100.2, U$5.15
RIGHT_IN_A: R62.2, U$2.1 (IN_A), U$4.P$19 (P0.8)
RIGHT_IN_B: R63.2, U$2.3 (IN_B), U$4.P$20 (P0.9)
RIGHT_OUT_A: JP4.2, U$2.7 (OUT_A)
RIGHT_OUT_B: JP4.1, U$2.5 (OUT_B)
R_ID: JP7.1, R23.1, R29.1
R_LED: JP7.3, R7.2
SCK: JP14.4, JP15.2, U$5.26
SCL: U$5.17
SDA: JP14.3, U$5.16
SI: JP15.5, U$5.28
SICS: U$5.25
SO: JP15.4, U$5.27
SP+: L12.2, U$5.31
SP+_OUT: C38.2, JP6.1, L12.1
SP-: L11.2, U$5.33
SP-_OUT: C39.2, JP6.2, L11.1
SWCLK: JP12.2, U$4.P$27 (P0.16), U$5.19
SWDIO: D14.A, JP12.3, U$4.P$31 (P0.20)
U8_VIN: C35.2, L9.1, U8.1 (VSS)
VCC_3: JP1.2, JP10.4, U$4.P$11 (P0.00)
VCC_33: C11.2, C31.2, JP12.4, JP15.1, U$4.P$8 (P0.28), U$5.2, U$5.4, U$5.7, U$5.23, U$5.32
VCC_ON: C37.+, D14.C, JP9.2, L13.1
VCV_M: C16.2, C17.2, C18.2, C19.2, C27.2, C28.2, F1.P$1 (1), JP9.3, U$1.4 (VCC), U$2.4 (VCC), U$3.4 (VCC)
VPP: JP14.1, U$5.1

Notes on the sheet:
LEFT
HEAD
should be 2920
Why is C11 all the way over here?!
TODO: * More cleanup * Check actual voltages * Try to identify voltage dividers * Re-Check SWDIO to Diode * Summarize Connections to NRF and Mystery Module
Totally not an NRF51822
Mystery Module
EXT_FLASH_SPI
SPEAKER OUT
ONE TIME PROGRAMMING I2C PORT
HEAD RGB LED
L & R LEG LEDS

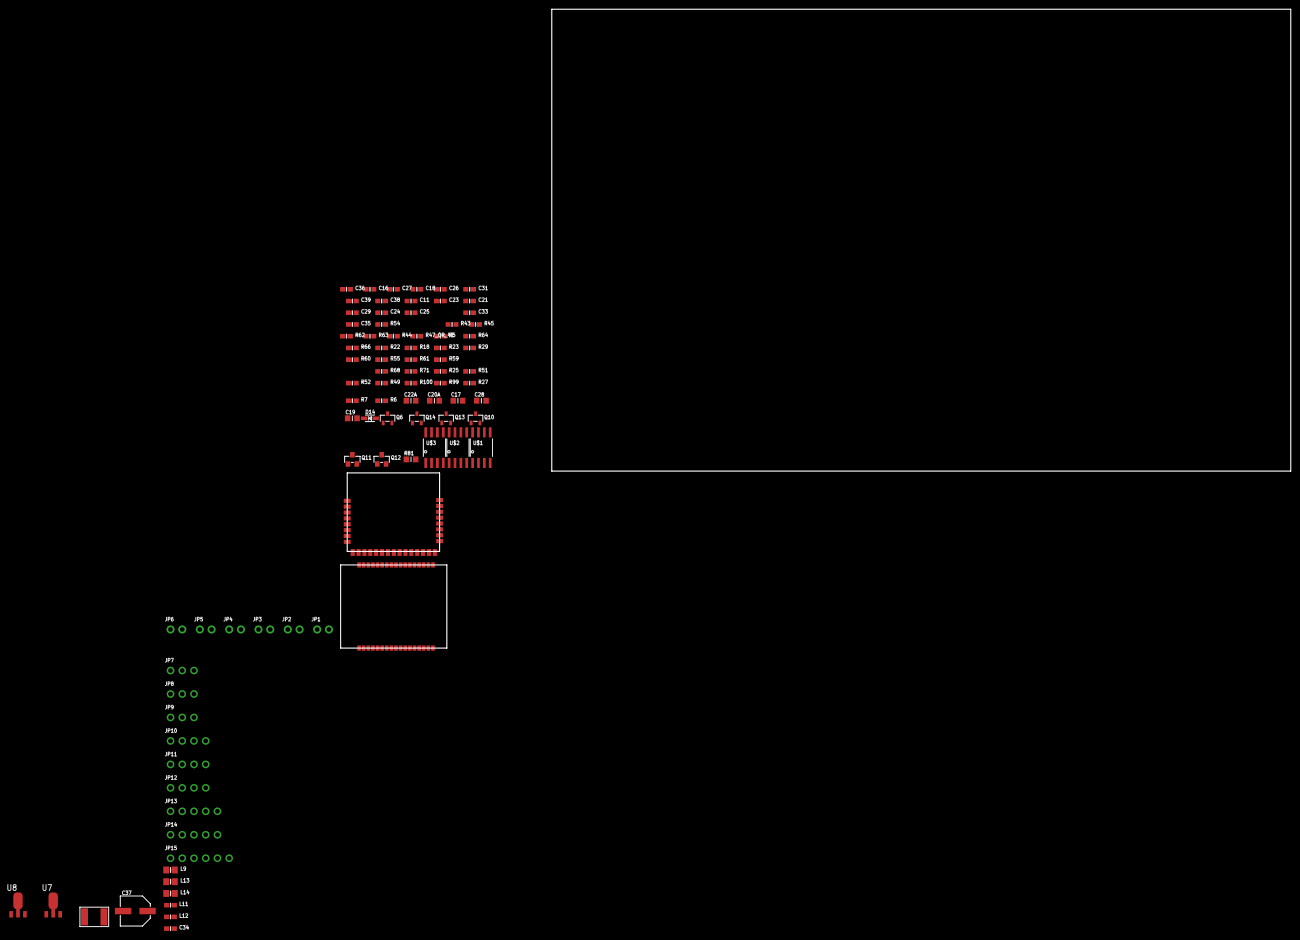
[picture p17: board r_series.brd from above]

Board: 2 copper layers, 205.7 x 138.3 mm, 88 parts (0 on the bottom side), 80 nets, no tracks yet.

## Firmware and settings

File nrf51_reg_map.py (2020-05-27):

#==========================================================================
#==========                      POWER                     ================
#==========================================================================


# IO Type Qualifier	Type	Description
# __IM	Struct member	Defines 'read only' permissions
# __OM	Struct member	Defines 'write only' permissions
# __IOM	Struct member	Defines 'read / write' permissions
# __I	Scalar variable	Defines 'read only' permissions
# __O	Scalar variable	Defines 'write only' permissions
# __IO	Scalar variable	Defines 'read / write' permissions

register_blocks = {
"POWER" : [
  ("R", 4, "RESERVED0", 30),
  ("W", 4, "TASKS_CONSTLAT"),                    # Enable constant latency mode.
  ("W", 4, "TASKS_LOWPWR"),                      # Enable low power mode (variable latency).
  ("R", 4, "RESERVED1", 34),
  ("RW", 4, "EVENTS_POFWARN"),                    # Power failure warning.
  ("R", 4, "RESERVED2", 126),
  ("RW", 4, "INTENSET"),                          # Interrupt enable set register.
  ("RW", 4, "INTENCLR"),                          # Interrupt enable clear register.
  ("R", 4, "RESERVED3", 61),
  ("RW", 4, "RESETREAS"),                         # Reset reason.
  ("R", 4, "RESERVED4", 9),
  ("R", 4, "RAMSTATUS"),                         # Ram status register.
  ("R", 4, "RESERVED5", 53),
  ("W", 4, "SYSTEMOFF"),                         # System off register.
  ("R", 4, "RESERVED6", 3),
  ("RW", 4, "POFCON"),                            # Power failure configuration.
  ("R", 4, "RESERVED7", 2),
  ("RW", 4, "GPREGRET"),                          # General purpose retention register. This register is a retained register.
  ("R", 4, "RESERVED8"),
  ("RW", 4, "RAMON"),                             # Ram on/off.
  ("R", 4, "RESERVED9", 7),
  ("RW", 4, "RESET"),                             # Pin reset functionality configuration register. This register is a retained register.
  ("R", 4, "RESERVED10", 3),
  ("RW", 4, "RAMONB"),                            # Ram on/off.
  ("R", 4, "RESERVED11", 8),
  ("RW", 4, "DCDCEN"),                            # DCDC converter enable configuration register.
  ("R", 4, "RESERVED12", 291),
  ("RW", 4, "DCDCFORCE"),                         # DCDC power-up force register.
  ("NRF_POWER_Type")
]


#==========================================================================
#==========                      CLOCK                     ================
# @brief Clock control. (CLOCK)
#==========================================================================
,
"CLOCK" : [
  ("W", 4, "TASKS_HFCLKSTART"),                  # Start HFCLK clock source.
  ("W", 4, "TASKS_HFCLKSTOP"),                   # Stop HFCLK clock source.
  ("W", 4, "TASKS_LFCLKSTART"),                  # Start LFCLK clock source.
  ("W", 4, "TASKS_LFCLKSTOP"),                   # Stop LFCLK clock source.
  ("W", 4, "TASKS_CAL"),                         # Start calibration of LFCLK RC oscillator.
  ("W", 4, "TASKS_CTSTART"),                     # Start calibration timer.
  ("W", 4, "TASKS_CTSTOP"),                      # Stop calibration timer.
  ("R", 4, "RESERVED0", 57),
  ("RW", 4, "EVENTS_HFCLKSTARTED"),               # HFCLK oscillator started.
  ("RW", 4, "EVENTS_LFCLKSTARTED"),               # LFCLK oscillator started.
  ("R", 4, "RESERVED1"),
  ("RW", 4, "EVENTS_DONE"),                       # Calibration of LFCLK RC oscillator completed.
  ("RW", 4, "EVENTS_CTTO"),                       # Calibration timer timeout.
  ("R", 4, "RESERVED2", 124),
  ("RW", 4, "INTENSET"),                          # Interrupt enable set register.
  ("RW", 4, "INTENCLR"),                          # Interrupt enable clear register.
  ("R", 4, "RESERVED3", 63),
  ("R", 4, "HFCLKRUN"),                          # Task HFCLKSTART trigger status.
  ("R", 4, "HFCLKSTAT"),                         # High frequency clock status.
  ("R", 4, "RESERVED4"),
  ("R", 4, "LFCLKRUN"),                          # Task LFCLKSTART triggered status.
  ("R", 4, "LFCLKSTAT"),                         # Low frequency clock status.
  ("R", 4, "LFCLKSRCCOPY"),                      # Clock source for the LFCLK clock, set when task LKCLKSTART is triggered.
  ("R", 4, "RESERVED5", 62),
  ("RW", 4, "LFCLKSRC"),                          # Clock source for the LFCLK clock.
  ("R", 4, "RESERVED6", 7),
  ("RW", 4, "CTIV"),                              # Calibration timer interval.
  ("R", 4, "RESERVED7", 5),
  ("RW", 4, "XTALFREQ"),                          # Crystal frequency.
  ("NRF_CLOCK_Type")
]


#==========================================================================
#==========                       MPU                      ================
# @brief Memory Protection Unit. (MPU)
#==========================================================================
,
"MPU" : [
  ("R", 4, "RESERVED0", 330),
  ("RW", 4, "PERR0"),                             # Configuration of peripherals in mpu regions.
  ("RW", 4, "RLENR0"),                            # Length of RAM region 0.
  ("R", 4, "RESERVED1", 52),
  ("RW", 4, "PROTENSET0"),                        # Erase and write protection bit enable set register.
  ("RW", 4, "PROTENSET1"),                        # Erase and write protection bit enable set register.
  ("RW", 4, "DISABLEINDEBUG"),                    # Disable erase and write protection mechanism in debug mode.
  ("RW", 4, "PROTBLOCKSIZE"),                     # Erase and write protection block size.
  ("NRF_MPU_Type")
],

#==========================================================================
#==========                    RADIO                     ================
# @brief The radio. (RADIO)
#==========================================================================
"RADIO" : [
  ("W", 4, "TASKS_TXEN"),                        # Enable radio in TX mode.
  ("W", 4, "TASKS_RXEN"),                        # Enable radio in RX mode.
  ("W", 4, "TASKS_START"),                       # Start radio.
  ("W", 4, "TASKS_STOP"),                        # Stop radio.
  ("W", 4, "TASKS_DISABLE"),                     # Disable radio.
  ("W", 4, "TASKS_RSSISTART"),                   # Start the RSSI and take one sample of the receive signal strength.
  ("W", 4, "TASKS_RSSISTOP"),                    # Stop the RSSI measurement.
  ("W", 4, "TASKS_BCSTART"),                     # Start the bit counter.
  ("W", 4, "TASKS_BCSTOP"),                      # Stop the bit counter.
  ("R", 4, "RESERVED0", 55),
  ("RW", 4, "EVENTS_READY"),                      # Ready event.
  ("RW", 4, "EVENTS_ADDRESS"),                    # Address event.
  ("RW", 4, "EVENTS_PAYLOAD"),                    # Payload event.
  ("RW", 4, "EVENTS_END"),                        # End event.
  ("RW", 4, "EVENTS_DISABLED"),                   # Disable event.
  ("RW", 4, "EVENTS_DEVMATCH"),                   # A device address match occurred on the last received packet.
  ("RW", 4, "EVENTS_DEVMISS"),                    # No device address match occurred on the last received packet.
  ("RW", 4, "EVENTS_RSSIEND"),                    # Sampling of the receive signal strength complete. A new RSSI sample is ready for readout at the RSSISAMPLE register.
  ("R", 4, "RESERVED1", 2),
  ("RW", 4, "EVENTS_BCMATCH"),                    # Bit counter reached bit count value specified in BCC register.
  ("R", 4, "RESERVED2", 53),
  ("RW", 4, "SHORTS"),                            # Shortcuts for the radio.
  ("R", 4, "RESERVED3", 64),
  ("RW", 4, "INTENSET"),                          # Interrupt enable set register.
  ("RW", 4, "INTENCLR"),                          # Interrupt enable clear register.
  ("R", 4, "RESERVED4", 61),
  ("R", 4, "CRCSTATUS"),                         # CRC status of received packet.
  ("R", 4, "RESERVED5"),
  ("R", 4, "RXMATCH"),                           # Received address.
  ("R", 4, "RXCRC"),                             # Received CRC.
  ("R", 4, "DAI"),                               # Device address match index.
  ("R", 4, "RESERVED6", 60),
  ("RW", 4, "PACKETPTR"),                         # Packet pointer. Decision point: START task.
  ("RW", 4, "FREQUENCY"),                         # Frequency.
  ("RW", 4, "TXPOWER"),                           # Output power.
  ("RW", 4, "MODE"),                              # Data rate and modulation.
  ("RW", 4, "PCNF0"),                             # Packet configuration 0.
  ("RW", 4, "PCNF1"),                             # Packet configuration 1.
  ("RW", 4, "BASE0"),                             # Radio base address 0. Decision point: START task.
  ("RW", 4, "BASE1"),                             # Radio base address 1. Decision point: START task.
  ("RW", 4, "PREFIX0"),                           # Prefixes bytes for logical addresses 0 to 3.
  ("RW", 4, "PREFIX1"),                           # Prefixes bytes for logical addresses 4 to 7.
  ("RW", 4, "TXADDRESS"),                         # Transmit address select.
  ("RW", 4, "RXADDRESSES"),                       # Receive address select.
  ("RW", 4, "CRCCNF"),                            # CRC configuration.
  ("RW", 4, "CRCPOLY"),                           # CRC polynomial.
  ("RW", 4, "CRCINIT"),                           # CRC initial value.
  ("RW", 4, "TEST"),                              # Test features enable register.
  ("RW", 4, "TIFS"),                              # Inter Frame Spacing in microseconds.
  ("R", 4, "RSSISAMPLE"),                        # RSSI sample.
  ("R", 4, "RESERVED7"),
  ("R", 4, "STATE"),                             # Current radio state.
  ("RW", 4, "DATAWHITEIV"),                       # Data whitening initial value.
  ("R", 4, "RESERVED8", 2),
  ("RW", 4, "BCC"),                               # Bit counter compare.
  ("R", 4, "RESERVED9", 39),
  ("RW", 4, "DAB", 8),                            # Device address base segment.
  ("RW", 4, "DAP", 8),                            # Device address prefix.
  ("RW", 4, "DACNF"),                             # Device address match configuration.
  ("R", 4, "RESERVED10", 56),
  ("RW", 4, "OVERRIDE0"),                         # Trim value override register 0.
  ("RW", 4, "OVERRIDE1"),                         # Trim value override register 1.
  ("RW", 4, "OVERRIDE2"),                         # Trim value override register 2.
  ("RW", 4, "OVERRIDE3"),                         # Trim value override register 3.
  ("RW", 4, "OVERRIDE4"),                         # Trim value override register 4.
  ("R", 4, "RESERVED11", 561),
  ("RW", 4, "POWER"),                             # Peripheral power control.
  ("NRF_RADIO_Type")
]


#==========================================================================
#==========                      UART                      ================
# @brief Universal Asynchronous Receiver/Transmitter. (UART)
#==========================================================================
,
"UART" : [
  ("W", 4, "TASKS_STARTRX"),                     # Start UART receiver.
  ("W", 4, "TASKS_STOPRX"),                      # Stop UART receiver.
  ("W", 4, "TASKS_STARTTX"),                     # Start UART transmitter.
  ("W", 4, "TASKS_STOPTX"),                      # Stop UART transmitter.
  ("R", 4, "RESERVED0", 3),
  ("W", 4, "TASKS_SUSPEND"),                     # Suspend UART.
  ("R", 4, "RESERVED1", 56),
  ("RW", 4, "EVENTS_CTS"),                        # CTS activated.
  ("RW", 4, "EVENTS_NCTS"),                       # CTS deactivated.
  ("RW", 4, "EVENTS_RXDRDY"),                     # Data received in RXD.
  ("R", 4, "RESERVED2", 4),
  ("RW", 4, "EVENTS_TXDRDY"),                     # Data sent from TXD.
  ("R", 4, "RESERVED3"),
  ("RW", 4, "EVENTS_ERROR"),                      # Error detected.
  ("R", 4, "RESERVED4", 7),
  ("RW", 4, "EVENTS_RXTO"),                       # Receiver timeout.
  ("R", 4, "RESERVED5", 46),
  ("RW", 4, "SHORTS"),                            # Shortcuts for UART.
  ("R", 4, "RESERVED6", 64),
  ("RW", 4, "INTENSET"),                          # Interrupt enable set register.
  ("RW", 4, "INTENCLR"),                          # Interrupt enable clear register.
  ("R", 4, "RESERVED7", 93),
  ("RW", 4, "ERRORSRC"),                          # Error source. Write error field to 1 to clear error.
  ("R", 4, "RESERVED8", 31),
  ("RW", 4, "ENABLE"),                            # Enable UART and acquire IOs.
  ("R", 4, "RESERVED9"),
  ("RW", 4, "PSELRTS"),                           # Pin select for RTS.
  ("RW", 4, "PSELTXD"),                           # Pin select for TXD.
  ("RW", 4, "PSELCTS"),                           # Pin select for CTS.
  ("RW", 4, "PSELRXD"),                           # Pin select for RXD.
  ("R", 4, "RXD"),                               # RXD register. On read action the buffer pointer is displaced. Once read the character is consumed. If read when no character  available, the UART will stop working.
  ("W", 4, "TXD"),                               # TXD register.
  ("R", 4, "RESERVED10"),
  ("RW", 4, "BAUDRATE"),                          # UART Baudrate.
  ("R", 4, "RESERVED11", 17),
  ("RW", 4, "CONFIG"),                            # Configuration of parity and hardware flow control register.
  ("R", 4, "RESERVED12", 675),
  ("RW", 4, "POWER"),                             # Peripheral power control.
  ("NRF_UART_Type")
]


#==========================================================================
#==========                       SPI                      ================
# @brief SPI master 0. (SPI)
#==========================================================================
,
"SPI" : [
  ("R", 4, "RESERVED0", 66),
  ("RW", 4, "EVENTS_READY"),                      # TXD byte sent and RXD byte received.
  ("R", 4, "RESERVED1", 126),
  ("RW", 4, "INTENSET"),                          # Interrupt enable set register.
  ("RW", 4, "INTENCLR"),                          # Interrupt enable clear register.
  ("R", 4, "RESERVED2", 125),
  ("RW", 4, "ENABLE"),                            # Enable SPI.
  ("R", 4, "RESERVED3"),
  ("RW", 4, "PSELSCK"),                           # Pin select for SCK.
  ("RW", 4, "PSELMOSI"),                          # Pin select for MOSI.
  ("RW", 4, "PSELMISO"),                          # Pin select for MISO.
  ("R", 4, "RESERVED4"),
  ("R", 4, "RXD"),                               # RX data.
  ("RW", 4, "TXD"),                               # TX data.
  ("R", 4, "RESERVED5"),
  ("RW", 4, "FREQUENCY"),                         # SPI frequency
  ("R", 4, "RESERVED6", 11),
  ("RW", 4, "CONFIG"),                            # Configuration register.
  ("R", 4, "RESERVED7", 681),
  ("RW", 4, "POWER"),                             # Peripheral power control.
  ("NRF_SPI_Type")
]


#==========================================================================
#==========                       TWI                      ================
# @brief Two-wire interface master 0. (TWI)
#==========================================================================
,
"TWI" : [
  ("W", 4, "TASKS_STARTRX"),                     # Start 2-Wire master receive sequence.
  ("R", 4, "RESERVED0"),
  ("W", 4, "TASKS_STARTTX"),                     # Start 2-Wire master transmit sequence.
  ("R", 4, "RESERVED1", 2),
  ("W", 4, "TASKS_STOP"),                        # Stop 2-Wire transaction.
  ("R", 4, "RESERVED2"),
  ("W", 4, "TASKS_SUSPEND"),                     # Suspend 2-Wire transaction.
  ("W", 4, "TASKS_RESUME"),                      # Resume 2-Wire transaction.
  ("R", 4, "RESERVED3", 56),
  ("RW", 4, "EVENTS_STOPPED"),                    # Two-wire stopped.
  ("RW", 4, "EVENTS_RXDREADY"),                   # Two-wire ready to deliver new RXD byte received.
  ("R", 4, "RESERVED4", 4),
  ("RW", 4, "EVENTS_TXDSENT"),                    # Two-wire finished sending last TXD byte.
  ("R", 4, "RESERVED5"),
  ("RW", 4, "EVENTS_ERROR"),                      # Two-wire error detected.
  ("R", 4, "RESERVED6", 4),
  ("RW", 4, "EVENTS_BB"),                         # Two-wire byte boundary.
  ("R", 4, "RESERVED7", 3),
  ("RW", 4, "EVENTS_SUSPENDED"),                  # Two-wire suspended.
  ("R", 4, "RESERVED8", 45),
  ("RW", 4, "SHORTS"),                            # Shortcuts for TWI.
  ("R", 4, "RESERVED9", 64),
  ("RW", 4, "INTENSET"),                          # Interrupt enable set register.
  ("RW", 4, "INTENCLR"),                          # Interrupt enable clear register.
  ("R", 4, "RESERVED10", 110),
  ("RW", 4, "ERRORSRC"),                          # Two-wire error source. Write error field to 1 to clear error.
  ("R", 4, "RESERVED11", 14),
  ("RW", 4, "ENABLE"),                            # Enable two-wire master.
  ("R", 4, "RESERVED12"),
  ("RW", 4, "PSELSCL"),                           # Pin select for SCL.
  ("RW", 4, "PSELSDA"),                           # Pin select for SDA.
  ("R", 4, "RESERVED13", 2),
  ("R", 4, "RXD"),                               # RX data register.
  ("RW", 4, "TXD"),                               # TX data register.
  ("R", 4, "RESERVED14"),
  ("RW", 4, "FREQUENCY"),                         # Two-wire frequency.
  ("R", 4, "RESERVED15", 24),
  ("RW", 4, "ADDRESS"),                           # Address used in the two-wire transfer.
  ("R", 4, "RESERVED16", 668),
  ("RW", 4, "POWER"),                             # Peripheral power control.
  ("NRF_TWI_Type")
]


#==========================================================================
#==========                      SPIS                      ================
# @brief SPI slave 1. (SPIS)
#==========================================================================
,
"SPIS" : [
  ("R", 4, "RESERVED0", 9),
  ("W", 4, "TASKS_ACQUIRE"),                     # Acquire SPI semaphore.
  ("W", 4, "TASKS_RELEASE"),                     # Release SPI semaphore.
  ("R", 4, "RESERVED1", 54),
  ("RW", 4, "EVENTS_END"),                        # Granted transaction completed.
  ("R", 4, "RESERVED2", 2),
  ("RW", 4, "EVENTS_ENDRX"),                      # End of RXD buffer reached
  ("R", 4, "RESERVED3", 5),
  ("RW", 4, "EVENTS_ACQUIRED"),                   # Semaphore acquired.
  ("R", 4, "RESERVED4", 53),
  ("RW", 4, "SHORTS"),                            # Shortcuts for SPIS.
  ("R", 4, "RESERVED5", 64),
  ("RW", 4, "INTENSET"),                          # Interrupt enable set register.
  ("RW", 4, "INTENCLR"),                          # Interrupt enable clear register.
  ("R", 4, "RESERVED6", 61),
  ("R", 4, "SEMSTAT"),                           # Semaphore status.
  ("R", 4, "RESERVED7", 15),
  ("RW", 4, "STATUS"),                            # Status from last transaction.
  ("R", 4, "RESERVED8", 47),
  ("RW", 4, "ENABLE"),                            # Enable SPIS.
  ("R", 4, "RESERVED9"),
  ("RW", 4, "PSELSCK"),                           # Pin select for SCK.
  ("RW", 4, "PSELMISO"),                          # Pin select for MISO.
  ("RW", 4, "PSELMOSI"),                          # Pin select for MOSI.
  ("RW", 4, "PSELCSN"),                           # Pin select for CSN.
  ("R", 4, "RESERVED10", 7),
  ("RW", 4, "RXDPTR"),                            # RX data pointer.
  ("RW", 4, "MAXRX"),                             # Maximum number of bytes in the receive buffer.
  ("R", 4, "AMOUNTRX"),                          # Number of bytes received in last granted transaction.
  ("R", 4, "RESERVED11"),
  ("RW", 4, "TXDPTR"),                            # TX data pointer.
  ("RW", 4, "MAXTX"),                             # Maximum number of bytes in the transmit buffer.
  ("R", 4, "AMOUNTTX"),                          # Number of bytes transmitted in last granted transaction.
  ("R", 4, "RESERVED12"),
  ("RW", 4, "CONFIG"),                            # Configuration register.
  ("R", 4, "RESERVED13"),
  ("RW", 4, "DEF"),                               # Default character.
  ("R", 4, "RESERVED14", 24),
  ("RW", 4, "ORC"),                               # Over-read character.
  ("R", 4, "RESERVED15", 654),
  ("RW", 4, "POWER"),                             # Peripheral power control.
  ("NRF_SPIS_Type")
]
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

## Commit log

2019-11-03 checking in locally at least
    [DROID.brd, DROID.sch]
2019-11-03 fixed passive names
    [DROID.brd, DROID.sch]
2019-11-03 more renames?
    [DROID.brd, DROID.sch]
2019-11-03 renamed nets to make connections easier
    [DROID.brd, DROID.sch]
2019-11-03 net name/connection updates
    [DROID.brd, DROID.sch]
2019-11-03 more nets/conns, addition parts
    [DROID.brd, DROID.sch]
2019-11-03 all components?
    [DROID.brd, DROID.sch]
2019-11-04 getti'n close
    [DROID.brd, DROID.sch]
2019-11-04 done for now
    [DROID.brd, DROID.sch]
2019-11-04 saving before cleanup
    [DROID.brd, DROID.sch]
2019-11-04 solved mystery net to motor R, added todos
    [DROID.brd, DROID.sch]
2019-11-09 adding library export
    [DROID.sch]
2019-11-09 moved parts to new lib
    [DROID.brd, DROID.sch]
2019-11-10 major reorganization
    [DROID.brd, DROID.sch]
2019-11-11 more organization
    [DROID.brd, DROID.sch]
2020-02-09 moar stuff
    [DROID_nosubs.brd, DROID_nosubs.sch]
2020-02-10 adding Russ's BB-8 schematic
2020-02-10 renaming the r-series files for clarity
    [r_series.brd, r_series.sch]
2020-05-07 adding readme and licenses
    [DROID_nosubs.brd, DROID_nosubs.sch]
